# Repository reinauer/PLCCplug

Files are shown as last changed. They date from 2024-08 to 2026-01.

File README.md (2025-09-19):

# PLCC plug

A parametric PLCC plug adapter created in OpenSCAD.

***
Please tell me about the use cases of this project.
***

<br />
<a href="images/plccplug84.jpg">
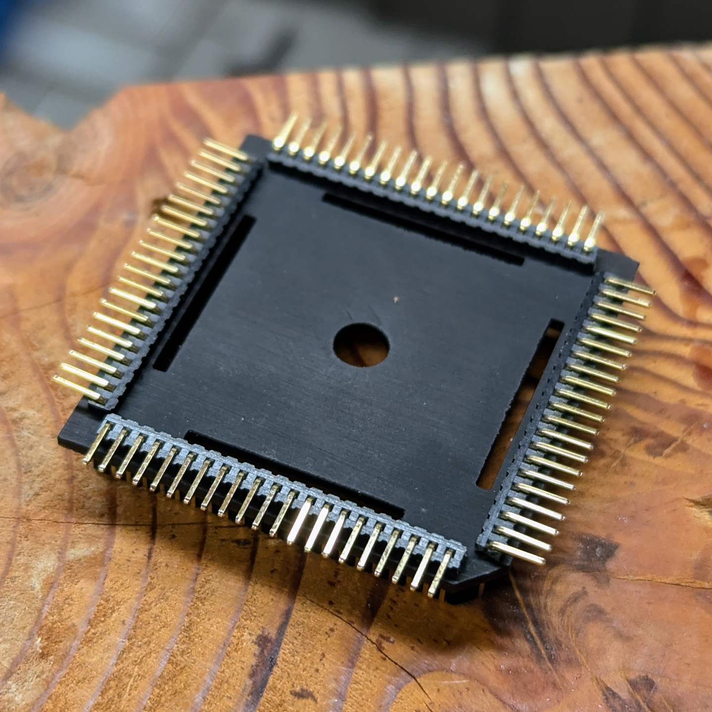
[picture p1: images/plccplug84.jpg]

</a>
<br />

This project includes
* STL files for 3D printing your own PLCC plugs
* Footprints and 3D models for KiCAD

## Prerequisites

You will need 4 pieces of 21pin 1.27mm Spacing (0.05")
Right Angle Male Pin Headers. Before pushing the into the plug's plastic
housing, be sure to push the pin header's plastic insulator all the way
to the bend all the way to the bend. I used uxcell pin headers with the
product number *a14081900ux0298*.

Other suitable pin headers to use with this plug:<br />
1.27 mm 50 P 1 x 50 Pin Header Single row Right Angle Male<br />
https://www.aliexpress.com/item/32767692043.html
<br />

## Printing

The PLCC plug is probably too fine pitched to print with an FDM printer.
I certainly did not succeed printing on a Prusa MK3s with 0.4mm nozzle.
A 0.2mm nozzle might yield more success. However, I suggest to print
these with nylon at a service like JLCPCB. Nylon is very heat resistent
and gives overall good results with dimensional stability and accuracy.
I also did some test prints in black resin at JLCPCB.

<br />
<a href="images/plug84angle.jpg">
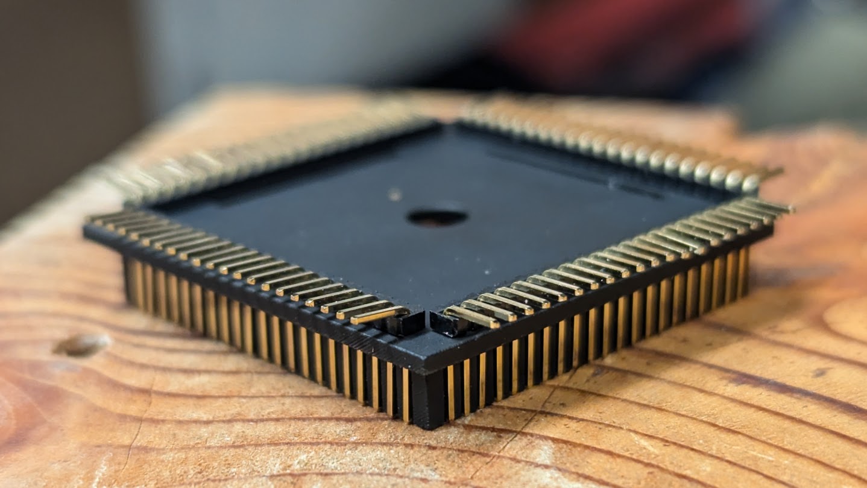
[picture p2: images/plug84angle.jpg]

</a>
<br />
Black resin print
<br />
<br />
<a href="images/plug84nylon.jpg">
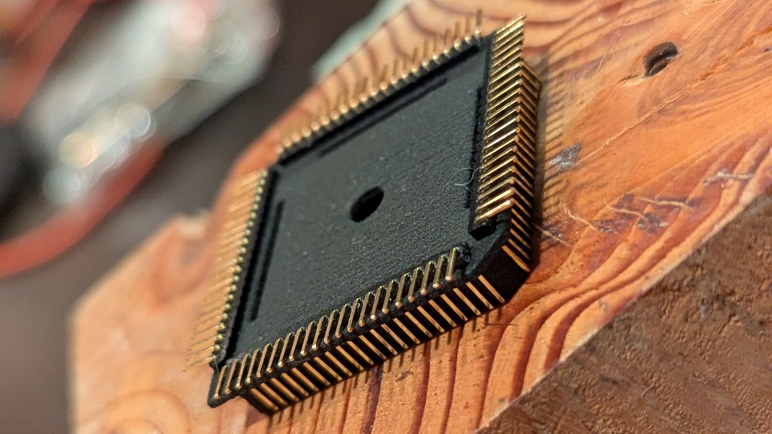
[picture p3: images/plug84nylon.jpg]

</a>
<br />
Nylon print
<br />

## KiCad

Copy PLCCplug.pretty and PLCCplug.3dshapes to your project and add
PLCCplug.pretty as a project local footprint library.

<br />
<a href="images/KiCad.png">
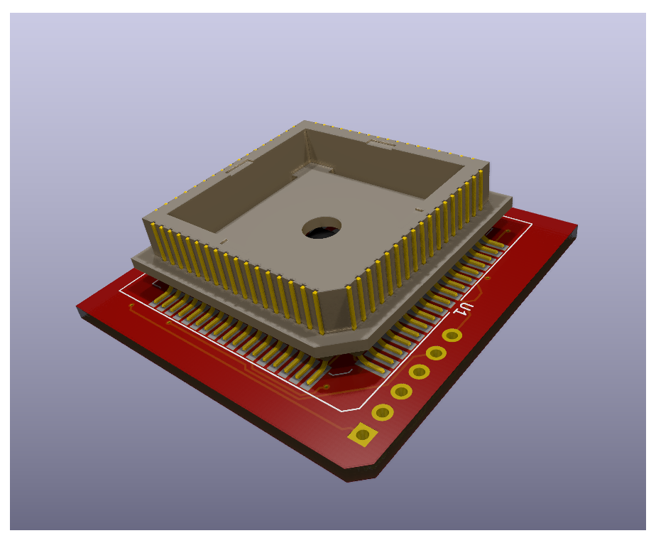
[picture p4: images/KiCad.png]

</a>
<br />
Sample KiCad rendering of PLCC plug in 68pin version
<br />

## Fitting

<br />
<a href="images/plug84socketfit.jpg">
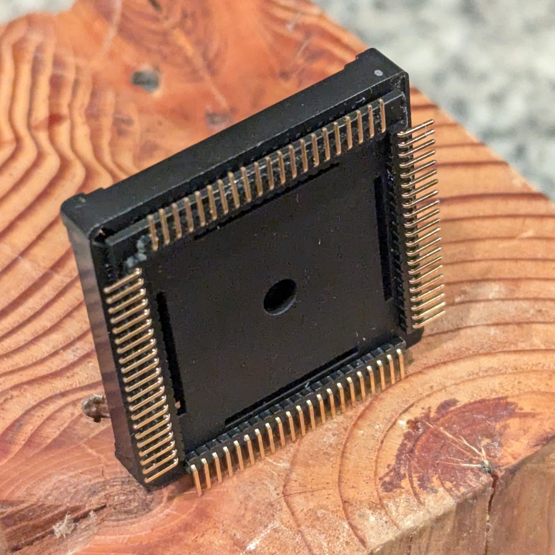
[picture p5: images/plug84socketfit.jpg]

</a>
<br />
Socket fitting
<br />
<br />
<a href="images/plug84pcbfit.jpg">
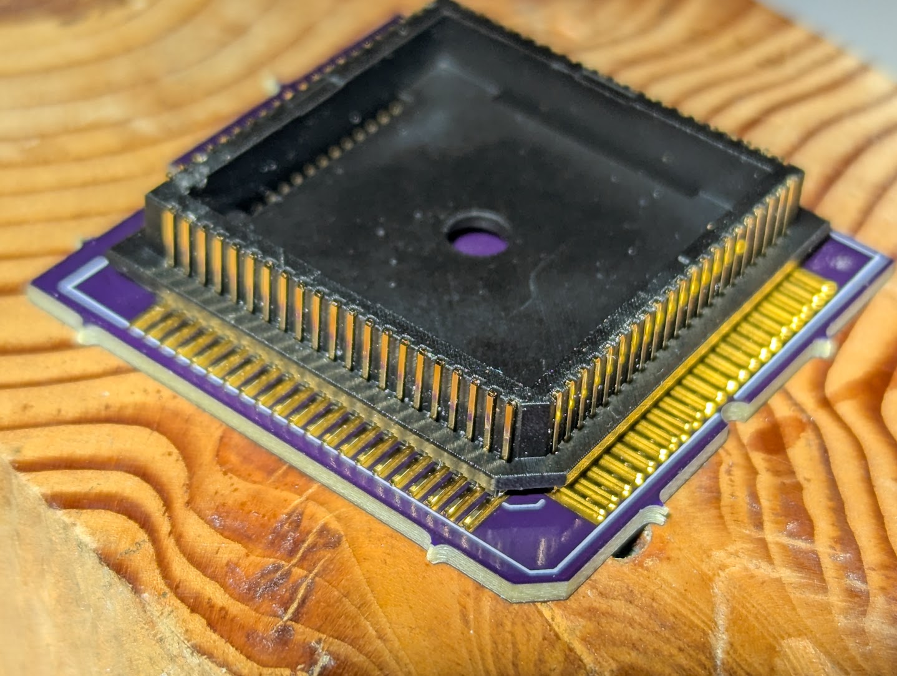
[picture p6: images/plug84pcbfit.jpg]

</a>
<br />
PCB fitting
<br />

***

[][cc-by-sa]

This work is licensed under a
[Creative Commons Attribution-ShareAlike 4.0 International License][cc-by-sa].

[][cc-by-sa]

[cc-by-sa]: http://creativecommons.org/licenses/by-sa/4.0/
[cc-by-sa-image]: https://licensebuttons.net/l/by-sa/4.0/88x31.png
[cc-by-sa-shield]: https://img.shields.io/badge/License-CC%20BY--SA%204.0-lightgrey.svg

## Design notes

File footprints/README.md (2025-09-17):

# PLCC Footprint Generator

This directory contains a C program (`plcc-gen.c`) that generates KiCAD footprints for Adapters-Plus APW932x series PLCC (Plastic Leaded Chip Carrier) plugs.

## Supported Components

The program generates footprints for 6 different PLCC plug models:

- **APW9328** (84 pins) - 36.6×36.6mm package
- **APW9327** (68 pins) - 30.10×30.10mm package
- **APW9326** (52 pins) - 25.10×25.10mm package
- **APW9325** (44 pins) - 22.50×22.50mm package
- **APW9324** (32 pins) - 17.40×19.90mm package
- **APW9323** (28 pins) - 17.40×17.40mm package
- **APW9322** (20 pins) - 15.00×15.00mm package

## Features

- Complete KiCAD `.kicad_mod` footprint files with:
  - Proper pad placement following PLCC standard
  - Silkscreen layer with pin 1 indicator
  - Courtyard and fabrication layers
  - 3D model references
- Configurable pad types (SMD or through-hole)
- Configurable via placement (inside/outside footprint)
- Dimensional data from component datasheets

## Pin Numbering

Follows PLCC standard with pin 1 located at the center of the top edge (marked with a notch), numbered sequentially clockwise around the package perimeter.

## Usage

1. Compile: `gcc -o plcc-gen plcc-gen.c`
2. Run: `./plcc-gen -p PINS [-o output_file]`

Where PINS is the number of pins (20, 28, 32, 44, 52, 68, or 84).

Examples:
- `./plcc-gen -p 84 > APW9328.kicad_mod`
- `./plcc-gen --pins 68 --outfile APW9327.kicad_mod`

## Configuration Options

- `COMPONENT_THROUGHHOLE`: 0 for SMD pads, 1 for through-hole pads
- `COMPONENT_VIA_OUTSIDE`: 0 for vias inside footprint, 1 for vias outside

## Reference

Based on Adapters-Plus APW932x series datasheet: https://www.adapt-plus.com/wp-content/uploads/2023/10/catalogpdf_51ba04f4f3329.pdf

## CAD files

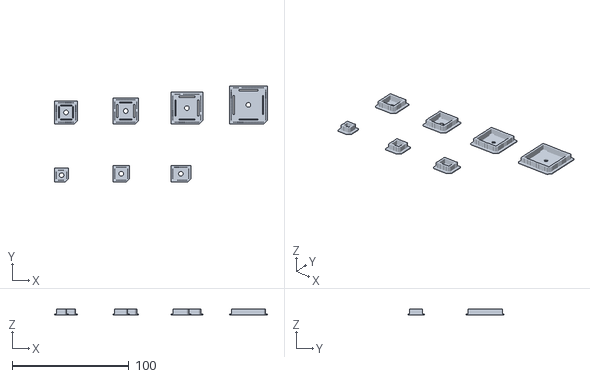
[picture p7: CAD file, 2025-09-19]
PLCCplug.stl/PLCCplug_all_versions.stl
182.8 x 82.8 x 5.50

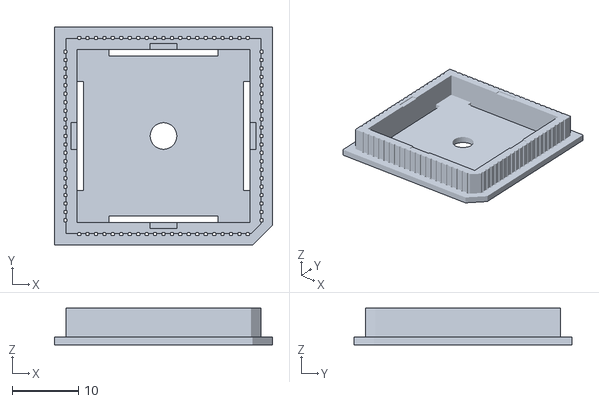
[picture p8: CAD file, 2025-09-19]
PLCCplug.stl/PLCCplug-84pin.stl
32.8 x 32.8 x 5.50

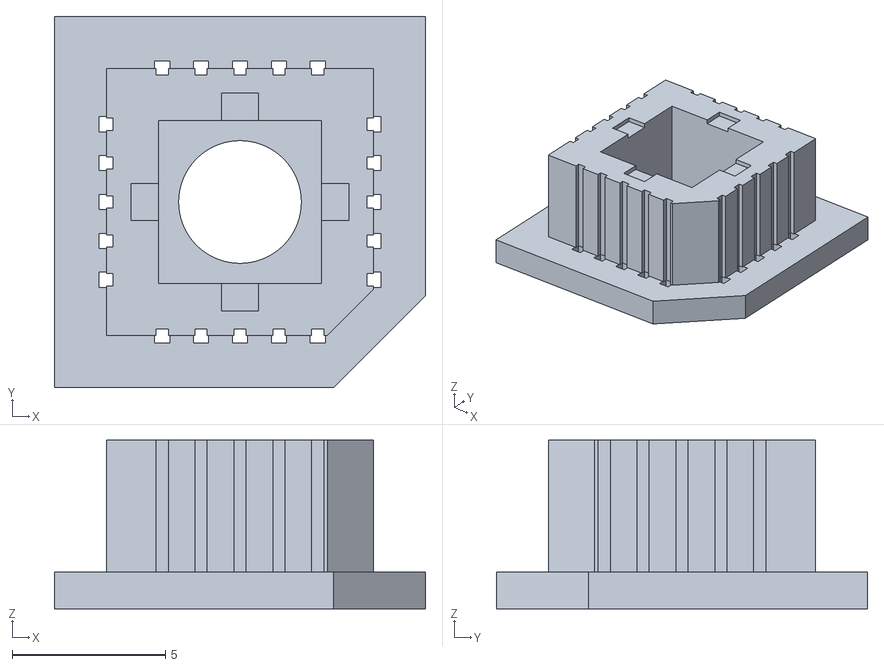
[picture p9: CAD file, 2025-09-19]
PLCCplug.stl/PLCCplug-20pin.stl
12.1 x 12.1 x 5.50

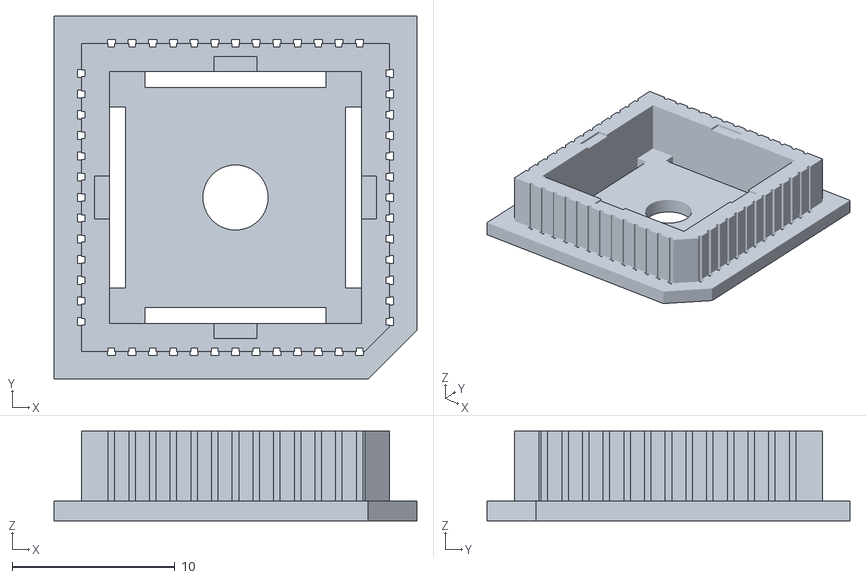
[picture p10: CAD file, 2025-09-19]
PLCCplug.stl/PLCCplug-52pin.stl
22.3 x 22.3 x 5.50

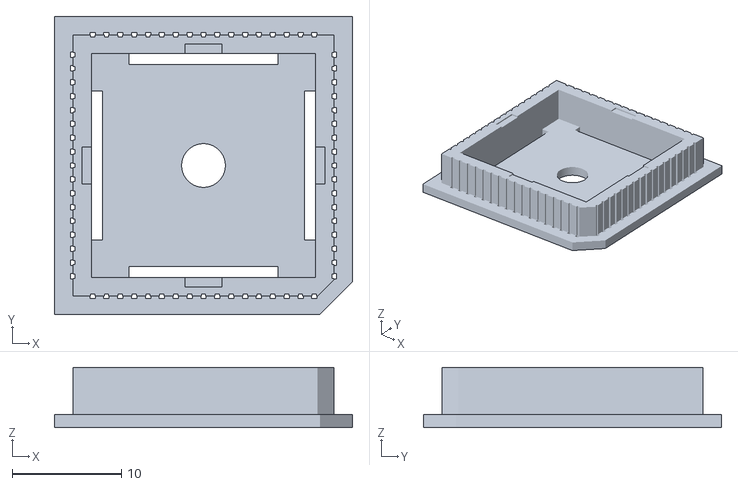
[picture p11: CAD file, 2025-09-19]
PLCCplug.stl/PLCCplug-68pin.stl
27.3 x 27.3 x 5.50

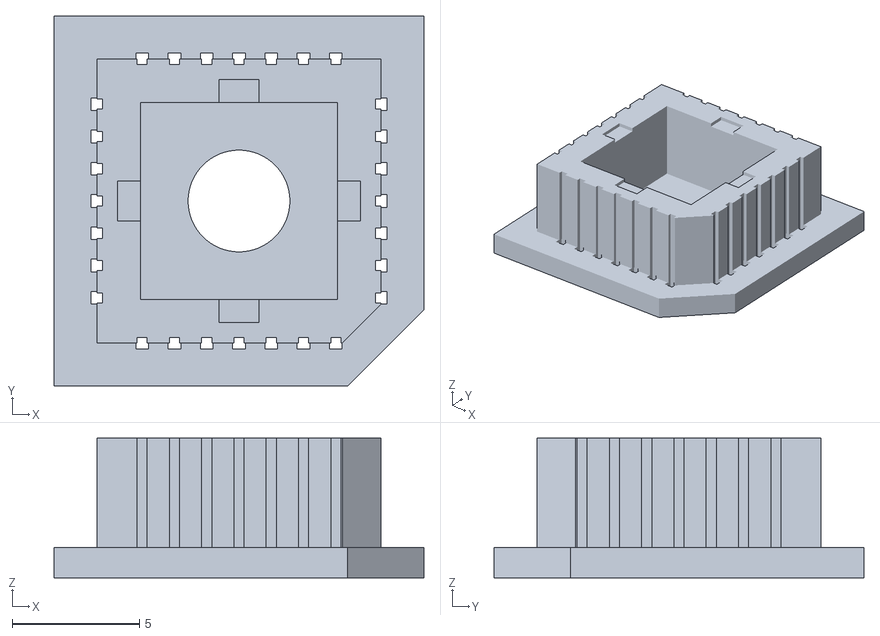
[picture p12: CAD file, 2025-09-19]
PLCCplug.stl/PLCCplug-28pin.stl
14.6 x 14.6 x 5.50

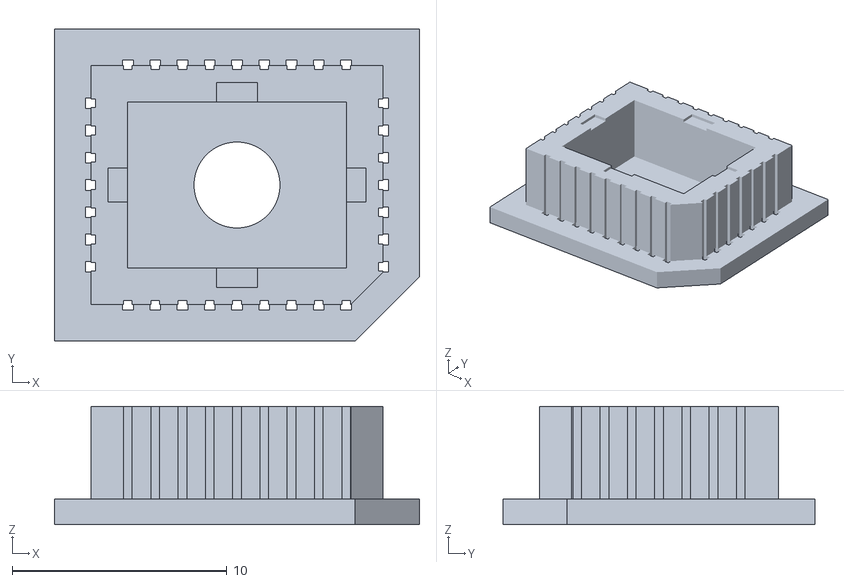
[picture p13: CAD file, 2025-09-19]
PLCCplug.stl/PLCCplug-32pin.stl
17.0 x 14.6 x 5.50

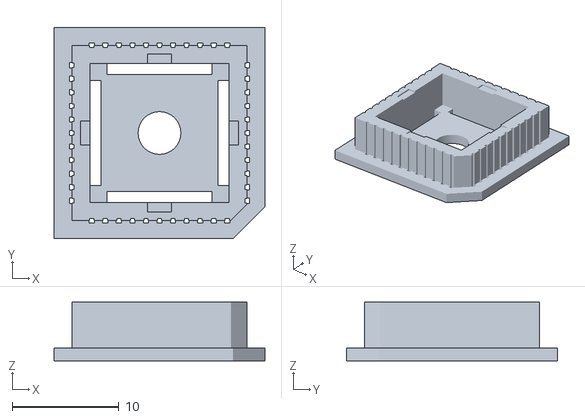
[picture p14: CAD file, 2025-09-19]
PLCCplug.stl/PLCCplug-44pin.stl
19.8 x 19.8 x 5.50

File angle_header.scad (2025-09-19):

//Customizable angle header
// by karfes - https://www.thingiverse.com/karfes/designs
// licensed under the Creative Commons - Attribution license.

translate([32.6,16.3,-2.35]) rotate([0,270,0])
  angle_header(rows=21,cols=1,pitch=1.27);
translate([16.3,32.6,-2.35]) rotate([90,270,0])
  angle_header(rows=21,cols=1,pitch=1.27);
translate([0,16.3,-2.35]) rotate([180,270,0])
  angle_header(rows=21,cols=1,pitch=1.27);
translate([16.3,0,-2.35]) rotate([270,270,0])
  angle_header(rows=21,cols=1,pitch=1.27);

module angle_header(rows,cols,pitch){
    offsety=((cols+1)*pitch)-((cols+1)*pitch)/2;
    offsetx=-1*((rows-1)/2*pitch);
    rotate([0,90,0])
    translate([0,offsetx,offsety])
    union(){
        for(j=[0:1:cols-1]){
            translate([-1*pitch*j,0,0])
            for(i=[0:1:rows-1]){
                translate([0,pitch*i,0])angle_pin(pitch,j);
            }
        }
    }
}
module angle_pin(pitch=2.54,col=0){
    rotate([90,0,0])corner(r=pitch, s=pitch, p=pitch,column=col);
    translate([-pitch,0,0])h_pin(p=pitch);
}
module corner(r=1,s=1,p=2.54,column=0){
    s=p/4+0.005;
    w=(r<1)?1:r*2;
    h=p*4-0.5;
    d=s/2;

    if(column==0){
        color("gold"){
        translate([0,-1*(p+d),d])rotate([0,90,0])cube([s,s,p],center=false);
        translate([p,-p,0])rotate([0,-90,0])mirror([0,0,d])
        rotate([0,0,45])cylinder($fn=4,r1=sqrt(2*pow(d,2)),r2=0,h=d,center=false);
        rotate_extrude($fn=100,angle=90)translate([-r,0,0])square(s,center=true);
        }
        translate([0,-1*(p+d),d])rotate([0,90,0])cube([s,s,p],center=false);
        translate([p,-p,0])
        rotate([0,-90,0])
        mirror([0,0,d])
        rotate([0,0,45])cylinder($fn=4,r1=sqrt(2*pow(d,2)),r2=0,h=d,center=false);
    }else{
        color("gold"){
        translate([-1*(p+d),0,-d])rotate([90,0,0])cube([s,s,p*column],center=false);
        translate([0,-column*p,0])
        rotate_extrude($fn=100,angle=90)translate([-r,0,0])square(s,center=true);
        }
        translate([0,-1*(column+1)*p-d,d])rotate([0,90,0])
        cube([s,s,(column+1)*p],center=false);
        translate([(column+1)*p,-1*(column+1)*p,0])
        rotate([0,-90,0])mirror([0,0,d])rotate([0,0,45])
        cylinder($fn=4,r1=sqrt(2*pow(d,2)),r2=0,h=d,center=false);
    }
}
module h_pin(p=2.54){
    s=p/4+0.005;
    h=p*4-0.5 +1.9;
    base=0.3;//h/3;
    //h=p*4-0.5;
    //base=h/3;
    d=s/2;
    union(){
        color("gold")union(){
            translate([0,0,h])rotate([0,0,45])
            cylinder($fn=4,r1=sqrt(2*pow(d,2)),r2=0,h=d,center=false);
            translate([-d,-d,0])cube([s,s,h],center=false);
        }
       color("Dimgray")difference(){
            translate([0,0,base+d])cube([p,p,p],center=true);
            union(){
            translate([1.9*s,1.9*s,base+d])rotate([0,0,45])
                cylinder($fn=3,r=2*d,h=p+1,center=true);
            translate([1.9*s,-1.9*s,base+d-0.15])rotate([0,0,-45])
                cylinder($fn=3,r=2*d,h=p+1,center=true);
            translate([-1.9*s,-1.9*s,base+d-0.3])rotate([0,0,180+45])
                cylinder($fn=3,r=2*d,h=p+1,center=true);
            translate([-1.9*s,1.9*s,base+d-0.3])rotate([0,0,180-45])
                cylinder($fn=3,r=2*d,h=p+1,center=true);
        }
    }
    }
}

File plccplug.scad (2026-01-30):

// PLCC plug model
// (C) 2020 Stefan Reinauer
// SPDX-License-Identifier: BSD-2-Clause
//
// OpenSCAD
//
//     /------------+
//    /       A     |
//    |  /--------+ |
//    |  |        | |
//    |  |B       | | D
//    |  |        | |
//    |  +--------+ |
//    |             |
//    +-------------+
//            C
//
//    =============== h2
//     |           |
//     |___________|  h1
//

use <angle_header.scad>

// distance between 2 pins
pin_pitch = 1.27;
// height of the bottom plate / plug
h1 = 4.3; // 4.45;
// height of the top plate
h2 = 1.2; // 1.47;

// 1.27mm pitch pins are 0.4mm, 2.54mm pitch pins are 0.64mm
//pinwidth=0.64;
pinwidth=0.4;

// edge - dimensions of the cutout triangle
edge_top = 3;
edge_bottom = 1.5;

// FDM printers with a very small nozzle size (0.2mm) might work
// So far resin and nylon prints have shown promising success. If
// you don't have a resin printer, you probably want to set this to 1:
clumsy_printer = 1;

/* test build all */
if (is_undef(scale_factor)) {
    scale_factor=1;
}
if (is_undef(output_pins)) {
  scale([scale_factor, scale_factor, scale_factor]) {
    translate([0,0,0]) plug(20);
    translate([50,0,0]) plug(28);
    translate([100,0,0]) plug(32);
    translate([0,50,0]) plug(44);
    translate([50,50,0]) plug(52);
    translate([100,50,0]) plug(68);
    translate([150,50,0]) plug(84);
  }
} else {
  scale([scale_factor, scale_factor, scale_factor])
     translate([0,0,0]) plug(output_pins);
}

// No user servicable parts inside
// Set the dimensions for the plug to be rendered and call render function
module plug(pins)
{
    echo (str("Rendering a ", pins, " pin PLCC plug"));
    if (pins == 20) { plccplug( 8.70, 8.70,12.10,12.10,5,5); } else
    if (pins == 28) { plccplug(11.15,11.15,14.55,14.55,7,7); } else
    if (pins == 32) { plccplug(13.60,11.15,17.00,14.55,9,7); } else

    if (pins == 44) { plccplug(16.40,16.40,19.80,19.80,11,11); } else
    if (pins == 52) { plccplug(18.90,18.90,22.30,22.30,13,13); } else
    if (pins == 68) { plccplug(23.90,23.90,27.30,27.30,17,17); } else
    if (pins == 84) { plccplug(29.40,29.40,32.80,32.80,21,21); }
}

// small prism to mark one side of the PLCC (cutout triangle)
//  l: length
//  w: width
//  h: height (top plate or bottom plate)
module corner(l, w, h)
{
    polyhedron(
               points=[[0,0,0], [l,0,0], [l,w,0],
                       [0,0,h], [l,0,h], [l,w,h]],
               faces=[[0,1,2],[5,4,3],[1,4,5,2],[0,3,4,1],[0,2,5,3]]
              );
}

module pin()
{
    // This was just a straight pin, like this:
    //   cube([pinwidth,pinwidth,h1+h2]);
    // But then a Prusa i3 MK3s can't make holes that small
    // on the top plate. So split the pin hole up in a tighter
    // section on the plug to keep the pin header in place, and
    // a wider one to allow printing this with your typical 3d
    // printer
    pin_tolerance = clumsy_printer ? 0.1 : 0;
    translate([-(pin_tolerance/2),-(pin_tolerance/2),0])
      cube([pinwidth + (pin_tolerance),pinwidth + (pin_tolerance),h2]);

    translate([0,0,h2])
      cube([pinwidth,pinwidth,h1]);

    translate([pinwidth/2,pinwidth/2,0])
      cylinder(h = h2, r1 = pin_pitch/2, r2 = 0, $fn = 64);
}

// Render a PLCC plug
//  A,B,C,D: dimensions of top plate and bottom plate
//  px: pins in x dimension
//  py: pins in y dimension
module plccplug(a,b,c,d,px,py)
{
    // all pins. p == pins
    p  = 2*py + 2*px;
    // space to the left and right of the socket part,
    // assuming the plug sits right in the middle of
    // the construct.
    dy=(c-a) / 2;
    dx=(d-b) / 2;
    // Thickness of the bottom plate walls in mm
    thickness=1.7;
    // width of the airgaps in mm (0 to disable)
    airgaps = (a < 15.0) ? 0 : 1;

    difference()
    {
        color("grey") {
            // bottom plate (plug)
            translate([dx,dy,h2]) {
                difference() {
                    cube([a,b,h1]);
                    // Cut off one corner
                    translate([a-edge_bottom,0,0])
                        corner (l=edge_bottom, w=edge_bottom, h=h1);
                    // cut a sqare hole in bottom plate
                    translate ([thickness, thickness, 0])
                        cube ([a - 2*thickness, b - 2*thickness, h1]);
                    // little notches on the hillside
                    translate([0.8,b*0.43,h1-0.2])
                        cube([a-1.6,b*0.14,0.2]);
                    translate([a*0.43,0.8,h1-0.2])
                        cube([a*0.14,b-1.6,0.2]);
                }
            }

            // top plate (lid)
            translate([0,0,0]) {
                difference() {
                    cube ([c,d,h2]);
                    translate([c-edge_top,0,0])
                        corner (l=edge_top, w=edge_top, h=h2);
                    // cut a cylinder in top plate
                    translate([c / 2, d / 2, 0])
                        cylinder (h = h2, r=2, $fn=100);
                    // fancy airgaps
                    if (airgaps) {
                        // 2/4
                        translate([c*0.25,thickness+dy,0])
                            cube([c/2,airgaps,h2]);
                        // 4/4
                        translate([c*0.25,d-(thickness+dy+airgaps),0])
                            cube([c/2,airgaps,h2]);
                        // 3/4
                        translate([dx + thickness,d*0.25,0])
                            cube([airgaps,d/2,h2]);
                        // 1/4 (Pin 1-)
                        translate([dx + a - thickness - airgaps,d*0.25,0])
                            cube([airgaps,d/2,h2]);
                    }
                }
            }
        }

        color("grey") translate([dx,dy,0])  {
            /* pin holes */
            // x and y shift calculation - determines the pin array origin
            // side length of plug - pin pitch * number of gaps between pins
            // divided by two

            x_shift = (a-(px-1)*pin_pitch)/2;
            y_shift = (b-(py-1)*pin_pitch)/2;

            // recess pins slightly
            recess = pinwidth/2;

            for( col  = [0: py-1 ] ) {
                translate( [-recess, y_shift - recess + (pin_pitch * col), 0] ) {
                    pin();
                }
            }

            for( col  = [0: py-1 ] ) {
                translate( [a-pinwidth+recess, y_shift - recess + (pin_pitch * col), 0] ) {
                    pin();
                }
            }

            for( row  = [0: px-1 ] ) {
                translate( [x_shift -recess + (pin_pitch * row), -recess, 0] ) {
                    pin();
                }
            }

            for( row  = [0: px-1 ] ) {
                translate( [x_shift - recess + (pin_pitch * row), b-pinwidth+recess, 0]) {
                    pin();
                }
            }
        }
    }
    if (!is_undef(render_pins)) {
        //Customizable angle header based on plug dimensions
        // Right header (vertical pins)
        translate([c - 0.4, d/2 - 0.025, -2.35]) rotate([0,270,0])
          angle_header(rows=py, cols=1, pitch=1.27);
        // Top header (horizontal pins)
        translate([c/2 - 0.025, d - 0.4, -2.35]) rotate([90,270,0])
          angle_header(rows=px, cols=1, pitch=1.27);
        // Left header (vertical pins)
        translate([0.4, d/2 - 0.025, -2.35]) rotate([180,270,0])
          angle_header(rows=py, cols=1, pitch=1.27);
        // Bottom header (horizontal pins)
        translate([c/2 - 0.025, 0.4, -2.35]) rotate([270,270,0])
          angle_header(rows=px, cols=1, pitch=1.27);
    }
}

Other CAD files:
angled_header.scad

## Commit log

2020-10-09 Initial release of PLCC plug
    [plccplug.scad]
2020-10-09 drop dead code
    [plccplug.scad]
2020-10-09 move some defines
    [plccplug.scad]
2020-10-09 move main work into plccplug module and parameters into plug module
    [plccplug.scad]
2020-10-10 fix appearance and geometry
    - turn around triangle cut out and move to right spot
    - define size of the triangle in edge_*
    - indent code
    - move cut outs in top and bottom plate to plate
    definition, leaving only pins below
    - fix position of the pin cut outs and make pin position
    relative to bottom plate
    [plccplug.scad]
2020-10-10 Make pin holes wider and add little notches
    [plccplug.scad]
2024-08-06 Add license
    [plccplug.scad]
2024-08-06 Add Makefile
    Add Makefile to build STLs for all PLCC plug versions
    and add the STLs produced.
    [plcc20.stl, plcc28.stl, plcc32.stl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]
2024-08-27 h1 and h2 were mixed up in the diagram
    [plccplug.scad]
2024-08-28 Adjust height of the plugs from 5.92mm to 5.5mm
    [plccplug.scad]
2024-08-28 improve documentation
    [plccplug.scad]
2024-08-28 Don't build all plugs demo if not building default
    make PINS=84 should not build plcc_all.stl
2024-08-28 Experiment with debug output
    [plccplug.scad]
2024-08-28 Make pin rendering configurable for different printer types
    [plccplug.scad]
2024-08-28 Footprint generator for KiCAD
2024-08-30 cleanup pins
    [plccplug.scad]
2024-08-30 Fix bottom cutout
    [plccplug.scad]
2024-08-30 Add comment
    [plccplug.scad]
2024-08-31 Add support for air gaps
    [plccplug.scad]
2024-08-31 Reduce size of the top plate
    [plccplug.scad]
2024-08-31 Recess half of the pins
    [plccplug.scad]
2024-08-31 Slightly adjust notches
    [plccplug.scad]
2024-08-31 Simplify plug() function
    [plccplug.scad]
2024-08-31 Test tolerance for Nylon prints
    [plccplug.scad]
2024-08-31 update STLs
    [plcc20.stl, plcc28.stl, plcc32.stl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]
2025-09-14 footprints: Add measurements for all pin counts
2025-09-14 footprints: Update generator
    - Generate Adapt Plus or Winslow footprints
    - Proper CLI
2025-09-14 footprints: Add options for double sided/single sided and VIA placement
2025-09-17 Improve footprint generator, and name it plcc-gen
2025-09-17 Make silkscreen fully dynamic
2025-09-17 Scale silkscreen layers
2025-09-17 Add angled header
    [angled_header.scad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]
2025-09-17 Fix pin headers for all plug sizes
    [plccplug.scad]
2025-09-19 Fine tune pin header position and colors
    [plccplug.scad]
2025-09-19 footprints: make destination configurable
    ... and change target to top level directory.
2025-09-19 footprints: Add correct path for 3d models
2025-09-19 Rework Makefile
    - Move STLs to PLCCplug.stl/
    - Move footprints to PLCCplug.pretty
    - Move 3D models for Kicad to PLCCplug.3dshapes
    [PLCCplug-20pin.stl, PLCCplug-28pin.stl, PLCCplug-32pin.stl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]
2025-09-19 Scale VRML files correctly
    [plccplug.scad]
2025-09-19 footprints: correct placement of the 3d models
2025-09-19 footprints: Fix 32pin variant
    The 32pin variant had 2 pins missing.
2025-09-19 Fix angle_header.scad attribution
    original file did not come with attribution, so I added
    a link to the original author's thingiverse page
    [angle_header.scad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]
2025-09-19 Fix pin offsets from plug body
    From mrgo0se:
    The current code to calculate the pin array offsets from the plug body
    appears to be incorrect. This gives slightly different distances between
    the first and last pin in each row and the closest corner on the plug
    body. i.e. the pin arrays are not centred on their respective sides of
    the plug resulting in an asymmetric model.
    [PLCCplug-20pin.stl, PLCCplug-28pin.stl, PLCCplug-32pin.stl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]
2026-01-30 Adding a cone at the pin locations to allow easing in the pin installation.
    [plccplug.scad]

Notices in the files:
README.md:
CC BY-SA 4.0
